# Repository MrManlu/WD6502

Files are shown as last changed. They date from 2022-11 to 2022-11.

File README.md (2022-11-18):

# WD6502
Prototyping SBC based on W65C02 CPU

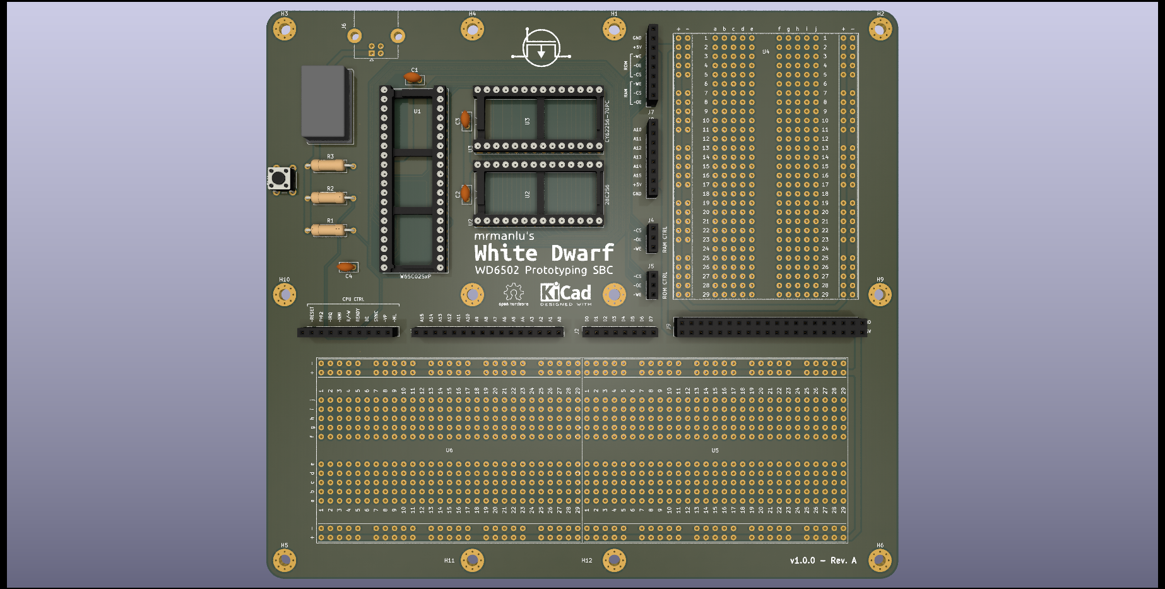
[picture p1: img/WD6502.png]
WD6502-PDB-front


## Why?
This is a minimal CPU<->RAM<->ROM interconnection to achieve a fast breadboard prototyping, minimizing bad connections occurred when connecting several jumper wires.

There is no fixed memory map. Freedom for everyone! There exists a half-sized breadboard in the upper-right zone of the PCB to create the address decoding circuit. Also, there exists a lower full-sized breadboard to connect peripherals: VIAs, ACIAs, SD card breakout boards,... 

## Contributing
This project is in its first steps. Feel free to contibute/fork as you want. **I'm a newbie in HW design, so please do constructive criticism!**

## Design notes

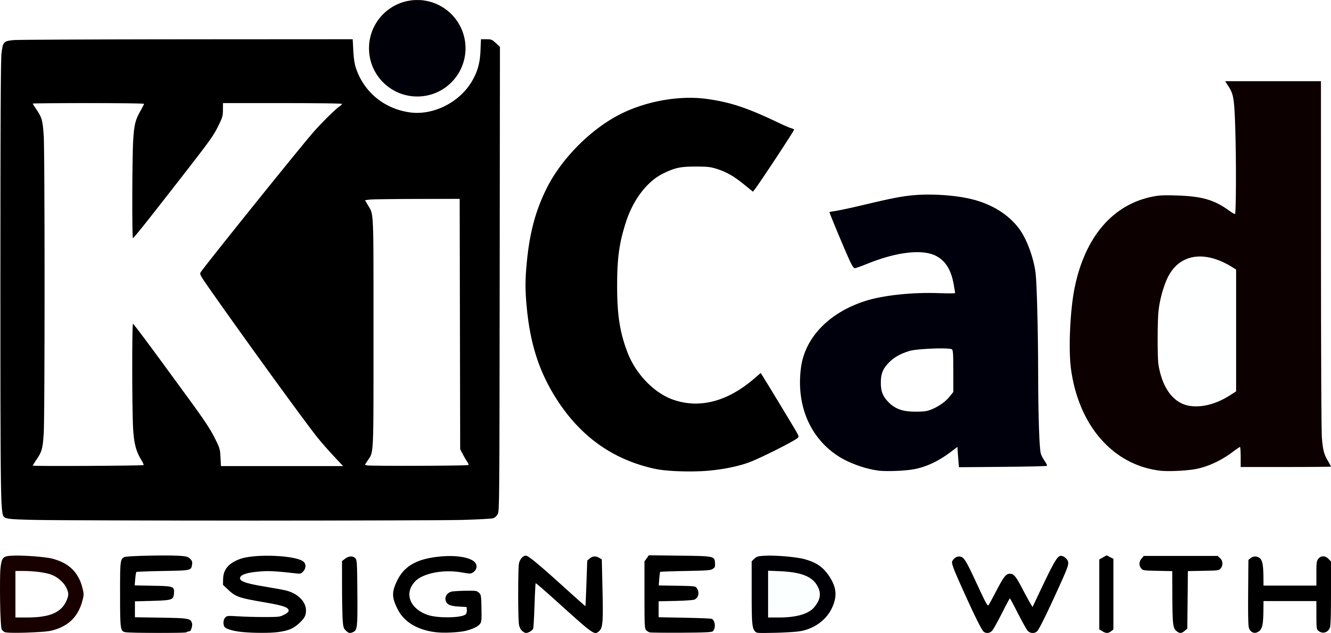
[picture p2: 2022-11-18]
kicad/designed-with-kicad.png

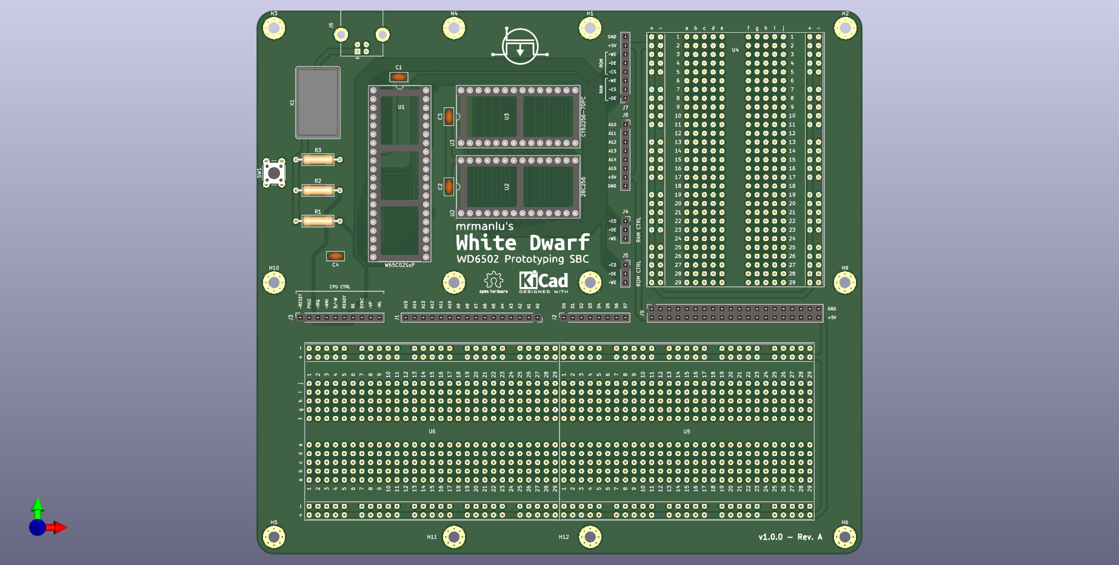
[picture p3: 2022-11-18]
img/WD6502-sketch.png

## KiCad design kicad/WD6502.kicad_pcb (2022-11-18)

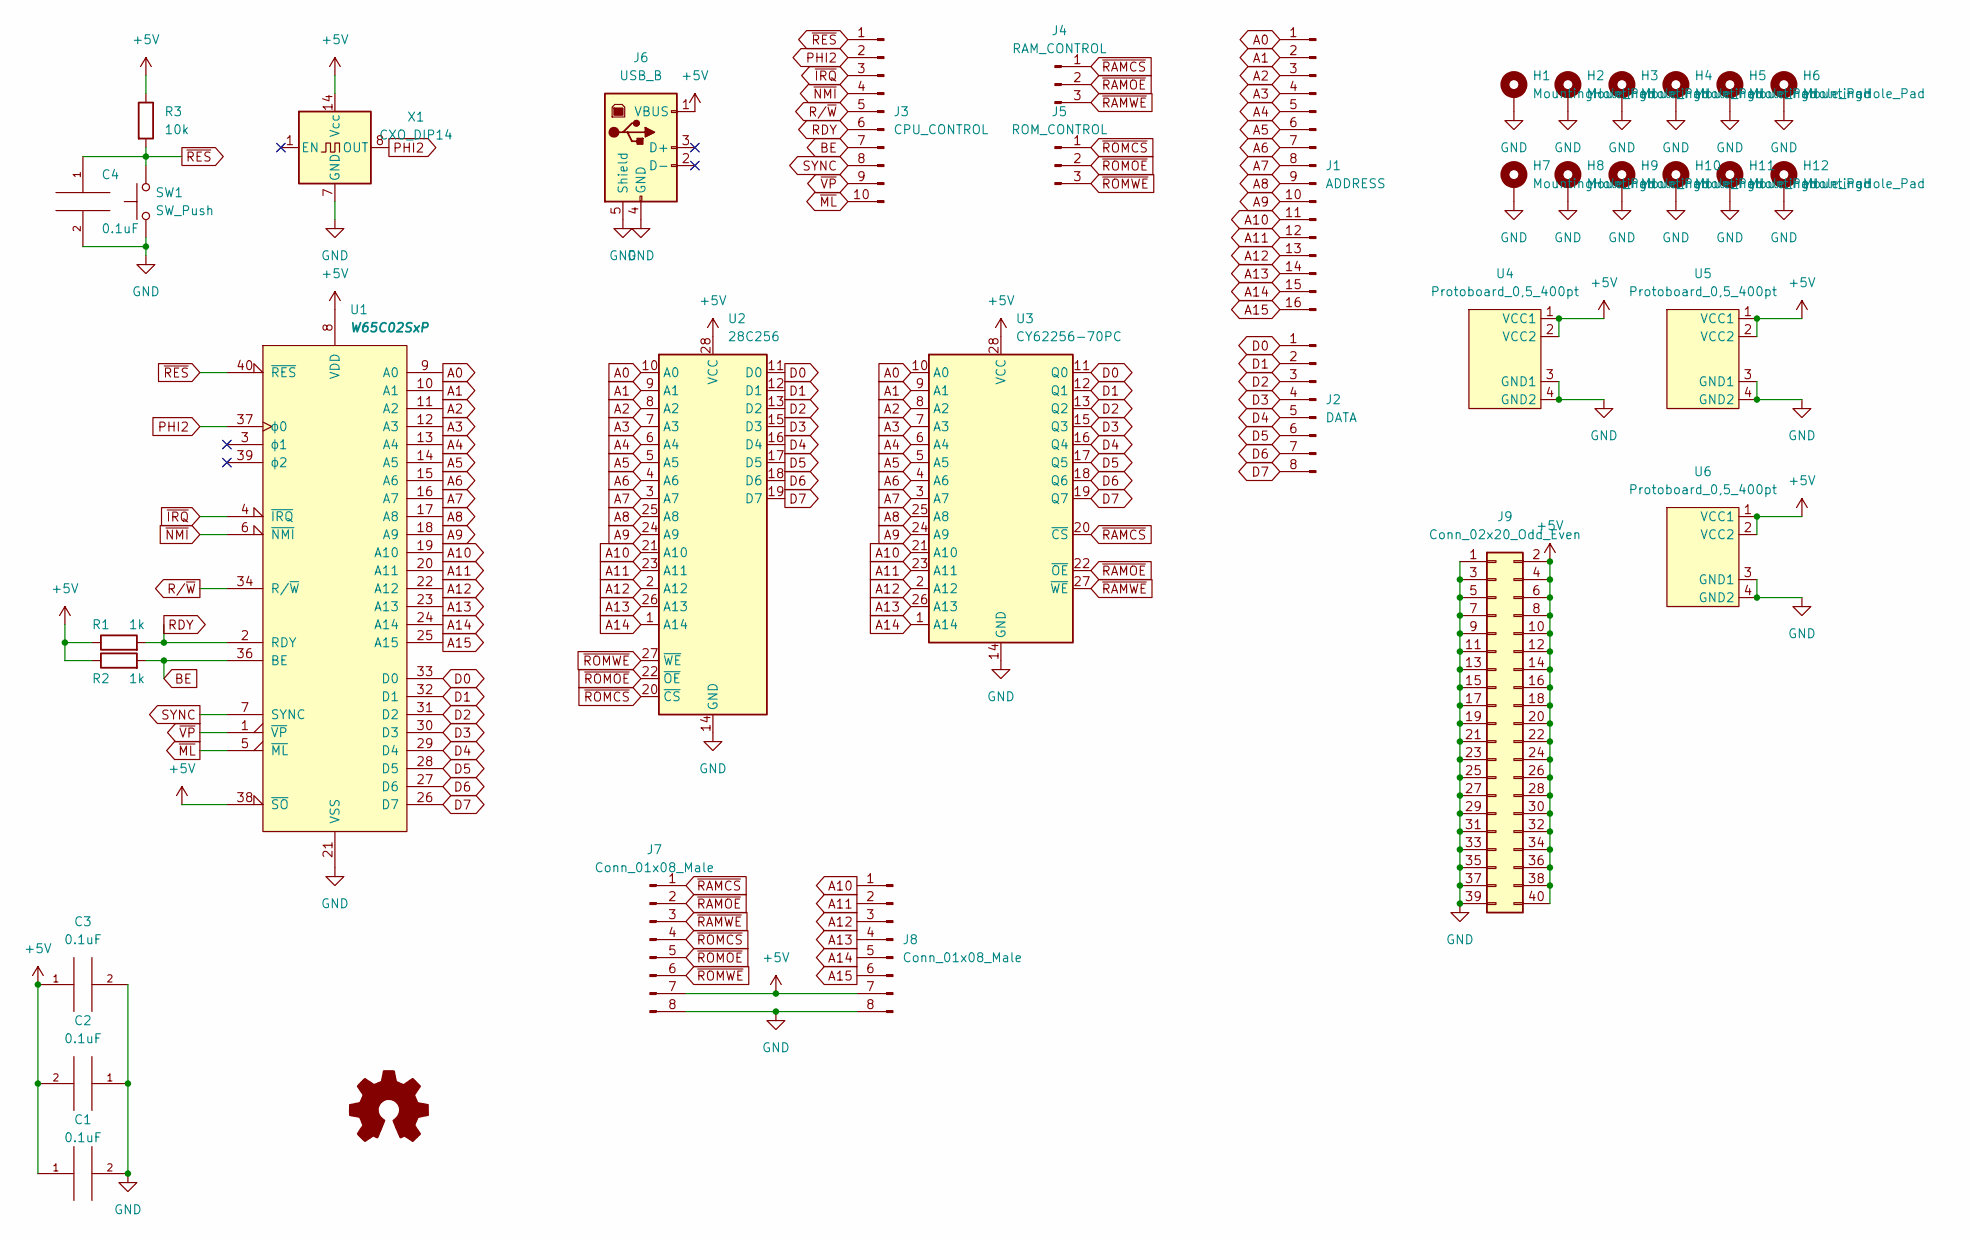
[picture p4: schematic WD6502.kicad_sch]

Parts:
C1, C2, C3, C4: 0.1uF; C_Disc_D5.0mm_W2.5mm_P2.50mm
H1, H2, H3, H4, H5, H6, H7, H8, H9, H10, H11, H12: MountingHole_Pad; MountingHole_3.2mm_M3_Pad_Via
J1: ADDRESS; PinSocket_1x16_P2.54mm_Vertical
J2: DATA; PinSocket_1x08_P2.54mm_Vertical
J3: CPU_CONTROL; PinSocket_1x10_P2.54mm_Vertical
J4: RAM_CONTROL; PinSocket_1x03_P2.54mm_Vertical
J5: ROM_CONTROL; PinSocket_1x03_P2.54mm_Vertical
J6: USB_B; USB_B_Lumberg_2411_02_Horizontal
J7, J8: Conn_01x08_Male; PinSocket_1x08_P2.54mm_Vertical
J9: Conn_02x20_Odd_Even; PinSocket_2x20_P2.54mm_Vertical
R1, R2: 1k; R_Axial_DIN0309_L9.0mm_D3.2mm_P12.70mm_Horizontal
R3: 10k; R_Axial_DIN0309_L9.0mm_D3.2mm_P12.70mm_Horizontal
SW1: SW_Push; SW_PUSH_6mm
U1: W65C02SxP; DIP-40_W15.24mm_Socket_LongPads
U2: 28C256; DIP-28_W15.24mm_Socket_LongPads
U3: CY62256-70PC; DIP-28_W15.24mm_Socket_LongPads
U4, U5, U6: Protoboard_0,5_400pt; Protoboard_Perfboard_0,5_400pt
X1: CXO_DIP14; Oscillator_DIP-14

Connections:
+5V: C1.1, C2.2, C3.1, J6.1 (VBUS), J7.7, J8.7, J9.2, J9.4, J9.6, J9.8, J9.10, J9.12, J9.14, J9.16, J9.18, J9.20, J9.22, J9.24, J9.26, J9.28, J9.30, J9.32, J9.34, J9.36, J9.38, J9.40, R1.1, R2.1, R3.1, U1.8 (VDD), U1.38 (~SO), U2.28 (VCC), U3.28 (VCC), U4.1 (VCC1), U4.2 (VCC2), U5.1 (VCC1), U5.2 (VCC2), U6.1 (VCC1), U6.2 (VCC2), X1.14 (Vcc)
A0: J1.1, U1.9 (A0), U2.10 (A0), U3.10 (A0)
A1: J1.2, U1.10 (A1), U2.9 (A1), U3.9 (A1)
A2: J1.3, U1.11 (A2), U2.8 (A2), U3.8 (A2)
A3: J1.4, U1.12 (A3), U2.7 (A3), U3.7 (A3)
A4: J1.5, U1.13 (A4), U2.6 (A4), U3.6 (A4)
A5: J1.6, U1.14 (A5), U2.5 (A5), U3.5 (A5)
A6: J1.7, U1.15 (A6), U2.4 (A6), U3.4 (A6)
A7: J1.8, U1.16 (A7), U2.3 (A7), U3.3 (A7)
A8: J1.9, U1.17 (A8), U2.25 (A8), U3.25 (A8)
A9: J1.10, U1.18 (A9), U2.24 (A9), U3.24 (A9)
A10: J1.11, J8.1, U1.19 (A10), U2.21 (A10), U3.21 (A10)
A11: J1.12, J8.2, U1.20 (A11), U2.23 (A11), U3.23 (A11)
A12: J1.13, J8.3, U1.22 (A12), U2.2 (A12), U3.2 (A12)
A13: J1.14, J8.4, U1.23 (A13), U2.26 (A13), U3.26 (A13)
A14: J1.15, J8.5, U1.24 (A14), U2.1 (A14), U3.1 (A14)
A15: J1.16, J8.6, U1.25 (A15)
BE: J3.7, R2.2, U1.36 (BE)
D0: J2.1, U1.33 (D0), U2.11 (D0), U3.11 (Q0)
D1: J2.2, U1.32 (D1), U2.12 (D1), U3.12 (Q1)
D2: J2.3, U1.31 (D2), U2.13 (D2), U3.13 (Q2)
D3: J2.4, U1.30 (D3), U2.15 (D3), U3.15 (Q3)
D4: J2.5, U1.29 (D4), U2.16 (D4), U3.16 (Q4)
D5: J2.6, U1.28 (D5), U2.17 (D5), U3.17 (Q5)
D6: J2.7, U1.27 (D6), U2.18 (D6), U3.18 (Q6)
D7: J2.8, U1.26 (D7), U2.19 (D7), U3.19 (Q7)
GND: C1.2, C2.1, C3.2, C4.2, H1.1, H2.1, H3.1, H4.1, H5.1, H6.1, H7.1, H8.1, H9.1, H10.1, H11.1, H12.1, J6.4 (GND), J6.5 (Shield), J7.8, J8.8, J9.1, J9.3, J9.5, J9.7, J9.9, J9.11, J9.13, J9.15, J9.17, J9.19, J9.21, J9.23, J9.25, J9.27, J9.29, J9.31, J9.33, J9.35, J9.37, J9.39, SW1.1, U1.21 (VSS), U2.14 (GND), U3.14 (GND), U4.3 (GND1), U4.4 (GND2), U5.3 (GND1), U5.4 (GND2), U6.3 (GND1), U6.4 (GND2), X1.7 (GND)
PHI2: J3.2, U1.37 (ϕ0), X1.8 (OUT)
RDY: J3.6, R1.2, U1.2 (RDY)
R/~W: J3.5, U1.34 (R/~W)
SYNC: J3.8, U1.7 (SYNC)
~IRQ: J3.3, U1.4 (~IRQ)
~ML: J3.10, U1.5 (~ML)
~NMI: J3.4, U1.6 (~NMI)
~RAMCS: J4.1, J7.1, U3.20 (~CS)
~RAMOE: J4.2, J7.2, U3.22 (~OE)
~RAMWE: J4.3, J7.3, U3.27 (~WE)
~RES: C4.1, J3.1, R3.2, SW1.2, U1.40 (~RES)
~ROMCS: J5.1, J7.4, U2.20 (~CS)
~ROMOE: J5.2, J7.5, U2.22 (~OE)
~ROMWE: J5.3, J7.6, U2.27 (~WE)
~VP: J3.9, U1.1 (~VP)

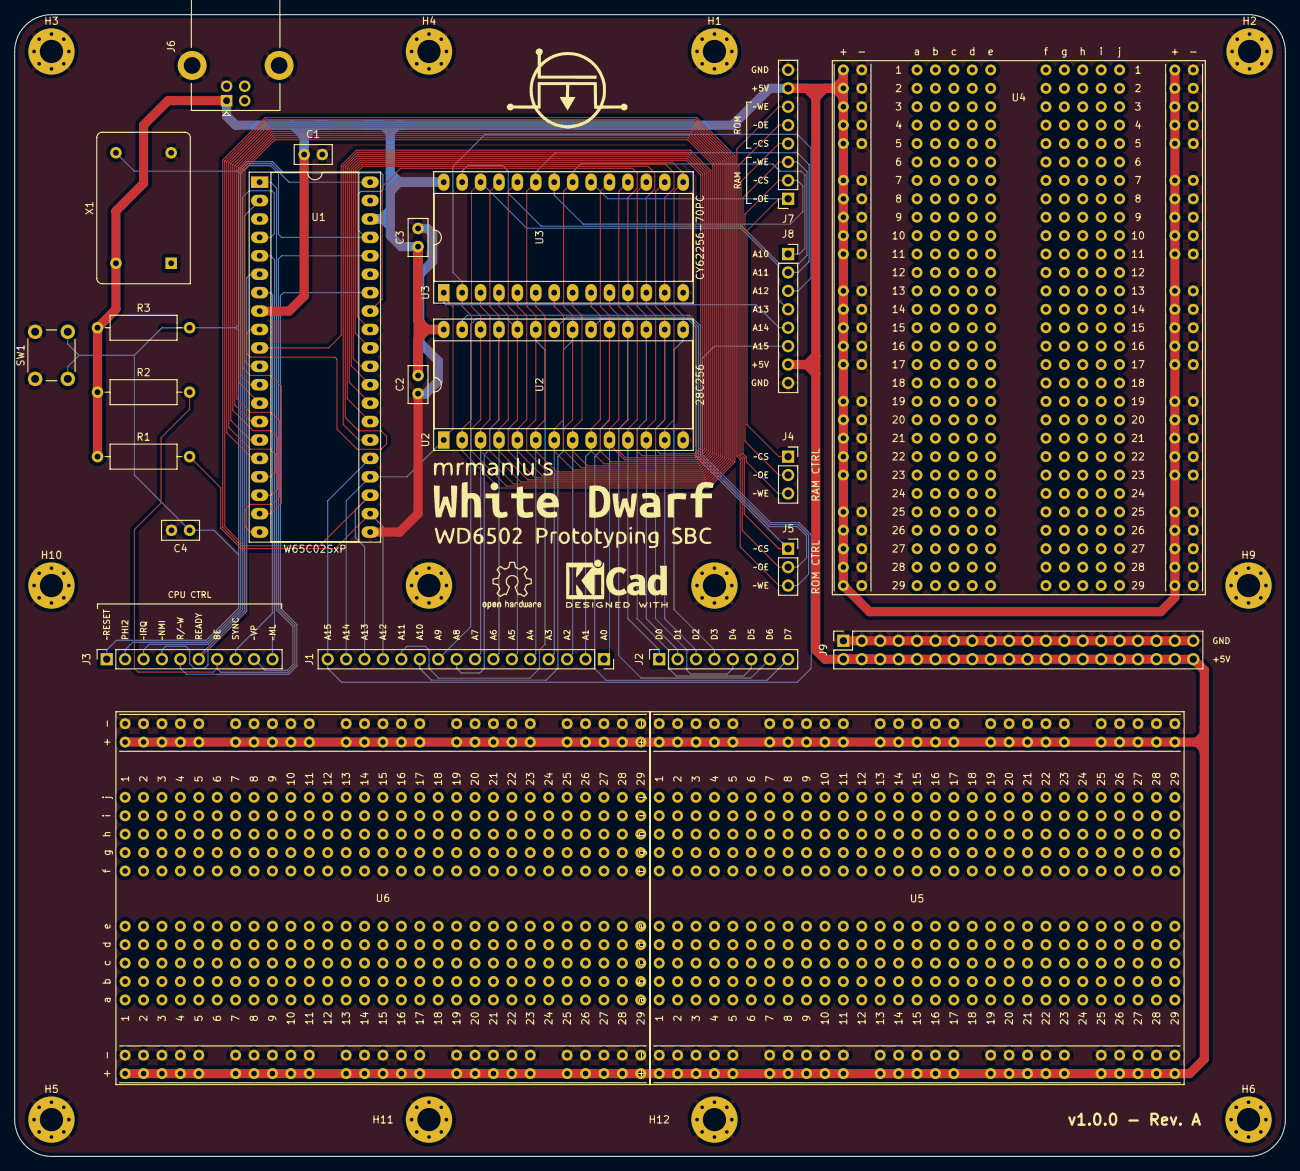
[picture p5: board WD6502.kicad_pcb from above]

Board: 2 copper layers, 175.3 x 157.5 mm, 36 parts (0 on the bottom side), 42 nets.
